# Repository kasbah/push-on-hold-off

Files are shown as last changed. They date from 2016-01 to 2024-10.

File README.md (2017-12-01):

See a preview of the board and buy the parts from the [kitspace.org page](https://kitspace.org/boards/github.com/kasbah/push-on-hold-off/). 

A power switch using a push button. It turns on with a single press and only turns off when you hold the button down. This could be used to get functionality similar to most laptops where a single press when on will initiate a "soft" shutdown but you can force a "hard" shutdown by holding it down.

The circuit is from [this article](http://www.mosaic-industries.com/embedded-systems/microcontroller-projects/electronic-circuits/push-button-switch-turn-on/latching-toggle-power-switch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).

The board is my own design and features:

- Standard 0.1" spacing, fits neatly onto a breadboard
- On-board button (and pins to connect your own)
- Two LEDs indicate input and output power
- Configurable to automatically turn on or stay off on initial power through a solder jumper (auto-off is the default)
- Can switch 3-20V and up to 4A

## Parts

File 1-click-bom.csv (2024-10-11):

References | Qty | Description | Manufacturer | MPN | Manufacturer | MPN | Manufacturer | MPN | Manufacturer | MPN | Manufacturer | MPN | Digikey | Mouser | RS | Newark | Farnell | LCSC | JLC Assembly
C1 | 1 | 1uF 0603 X5R | Murata | GRM188R71E224KA88D | KEMET | C0603C105K8PACTU | Yageo | CC0603KRX5R6BB105 |  |  |  |  | 399-C0603C105K8PAC7867DKR-ND | 603CC603KRX5R6BB105 | 4612708 | 91R0949 | 9402080 | C77051
C2 | 1 | 10uF 0603 X5R | TDK | C1608X5R1A106M080AC |  | 06036D106MAT2A | AVX | 06036D106MAT2A | TDK | C1608X5R0J106K080AB | TDK | C1608X5R1A106K080AC | 478-5318-6-ND | 810C1608X5R1A106K | 7882887P | 04X3239 | 2211164 | C3877917
C4 | 1 | 0.1uF 0603 X5R | Kemet | C0603C104K5RACTU | Murata | GRM033R60J104KE19D | KEMET | C0603C104K5RACTU |  |  |  |  | 490-3167-6-ND | 81GRM033R60J104KE19 | 8015347 | 72J5992 | 1288255 | C127833
D1 | 1 | Diode MiniMELF |  | LL4148 | onsemi | FDLL4148 | Diotec | LL4148 | onsemi | LL4148 |  |  | LL4148FSCT-ND | 512LL4148 | 6708823 | 14M6003 | 2356382 | C3011166
LED1,LED2 | 2 | 0603 20mA yellow | Rohm | SML-D12Y8WT86 | Dialight | 598-8040-107F | Dialight | 598-8150-107F | ROHM | SML-D12Y8WT86 |  |  | 350-2032-6-ND | 755SMLD12Y8WT86 | 7008039P | 75R0585 | 1867104 | C2840179
Q1 | 1 | 30V Vds, 3A Id, Dual HEXFET MOSFET | International Rectifier | IRF7309PBF | Infineon | IRF7309TRPBF |  |  |  |  |  |  | IRF7309PBFTR-ND | 942IRF7309TRPBF | 8268866 | 19K8239 | 2468006 | C3289674
R1 | 1 | 10k 0603 | Vishay | CRCW060310K0JNEA | Vishay | CRCW060310K0JNEAIF |  |  |  |  |  |  | 541-10KAQCT-ND | 71CRCW060310K0JNEAI | 8206928 | 52K8066 | 1739174 | C169103
R2,R4 | 2 | 100k 0603 | Vishay | CRCW0603100KJNEA | Vishay | CRCW0603100KJNEAIF |  |  |  |  |  |  | 541-100KAQDKR-ND | 71CRCW0603100KJNAIF | 8206916P | 59M6763 | 1692517 | C844723
R3 | 1 | 300k 0603 | Vishay | CRCW0603300KFKEA | Yageo | RC0603JR-07300KL |  |  |  |  |  |  | 311-300KGRCT-ND | 603RC0603JR07300KL | 6790178 | 52K8409 | 3495948 | C844772
R5, R6 | 2 | 1k 0603 | Yageo | RC0805FR-071KL |  |  |  |  |  |  |  |  | 311-1.00KCRDKR-ND | 603RC0805FR071KL | 6183583 | 82K7536 | 9237496 | C95781
SW1 | 1 | Tactile switch |  | FSM2JSMA | TE Connectivity | 2-1437565-7 |  |  |  |  |  |  | 450-1130-ND | 506FSM2JSMA | 4791491P | 92F2864 | 3801287 | C7193797

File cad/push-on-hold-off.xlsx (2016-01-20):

 |  |  |  |  |  |  | Board Qty: | 100
 |  |  |  |  |  |  | Total Cost: | $0.00 |  |  |  | $0.00 |  |  |  |  |  | $0.00 |  |  |  |  |  | $0.00
 |  |  |  |  |  |  | Unit Cost: | $0.00
Global Part Info |  |  |  |  |  |  |  |  | Digi-Key |  |  |  |  |  | Mouser |  |  |  |  |  | Newark
Refs | Value | Desc | Footprint | Manf | Manf# | Qty | Unit$ | Ext$ | Avail | Purch | Unit$ | Ext$ | Cat# | Doc | Avail | Purch | Unit$ | Ext$ | Cat# | Doc | Avail | Purch | Unit$ | Ext$ | Cat# | Doc
SW1 | SW_PUSH_SMALL |  |  |  |  | 0 | $0.00 | $0.00
C1 | 1uF |  |  |  |  | 0 | $0.00 | $0.00
C2 | 10uF |  |  |  |  | 0 | $0.00 | $0.00
R3 | 300k |  |  |  |  | 0 | $0.00 | $0.00
Q1 | IRF7309IPBF |  | SO-8 |  |  | 0 | $0.00 | $0.00
R2,R4 | 100k |  |  |  |  | 0 | $0.00 | $0.00
R1 | 10k |  |  |  |  | 0 | $0.00 | $0.00
P1,P2 | CONN_01X04 |  |  |  |  | 0 | $0.00 | $0.00
D1 | D |  |  |  |  | 0 | $0.00 | $0.00
 |  |  |  |  |  |  |  |  |  | 0 | 0 | 0 |  |  |  | 0 | 0 | 0 |  |  |  | 0 | 0 | 0
 |  |  |  |  |  |  |  |  |  | 0 | 0 | 0 |  |  |  | 0 | 0 | 0 |  |  |  | 0 | 0 | 0
 |  |  |  |  |  |  |  |  |  | 0 | 0 | 0 |  |  |  | 0 | 0 | 0 |  |  |  | 0 | 0 | 0
 |  |  |  |  |  |  |  |  |  | 0 | 0 | 0 |  |  |  | 0 | 0 | 0 |  |  |  | 0 | 0 | 0
 |  |  |  |  |  |  |  |  |  | 0 | 0 | 0 |  |  |  | 0 | 0 | 0 |  |  |  | 0 | 0 | 0
 |  |  |  |  |  |  |  |  |  | 0 | 0 | 0 |  |  |  | 0 | 0 | 0 |  |  |  | 0 | 0 | 0
 |  |  |  |  |  |  |  |  |  | 0 | 0 | 0 |  |  |  | 0 | 0 | 0 |  |  |  | 0 | 0 | 0
 |  |  |  |  |  |  |  |  |  | 0 | 0 | 0 |  |  |  | 0 | 0 | 0 |  |  |  | 0 | 0 | 0
 |  |  |  |  |  |  |  |  |  | 0 | 0 | 0 |  |  |  | 0 | 0 | 0 |  |  |  | 0 | 0 | 0

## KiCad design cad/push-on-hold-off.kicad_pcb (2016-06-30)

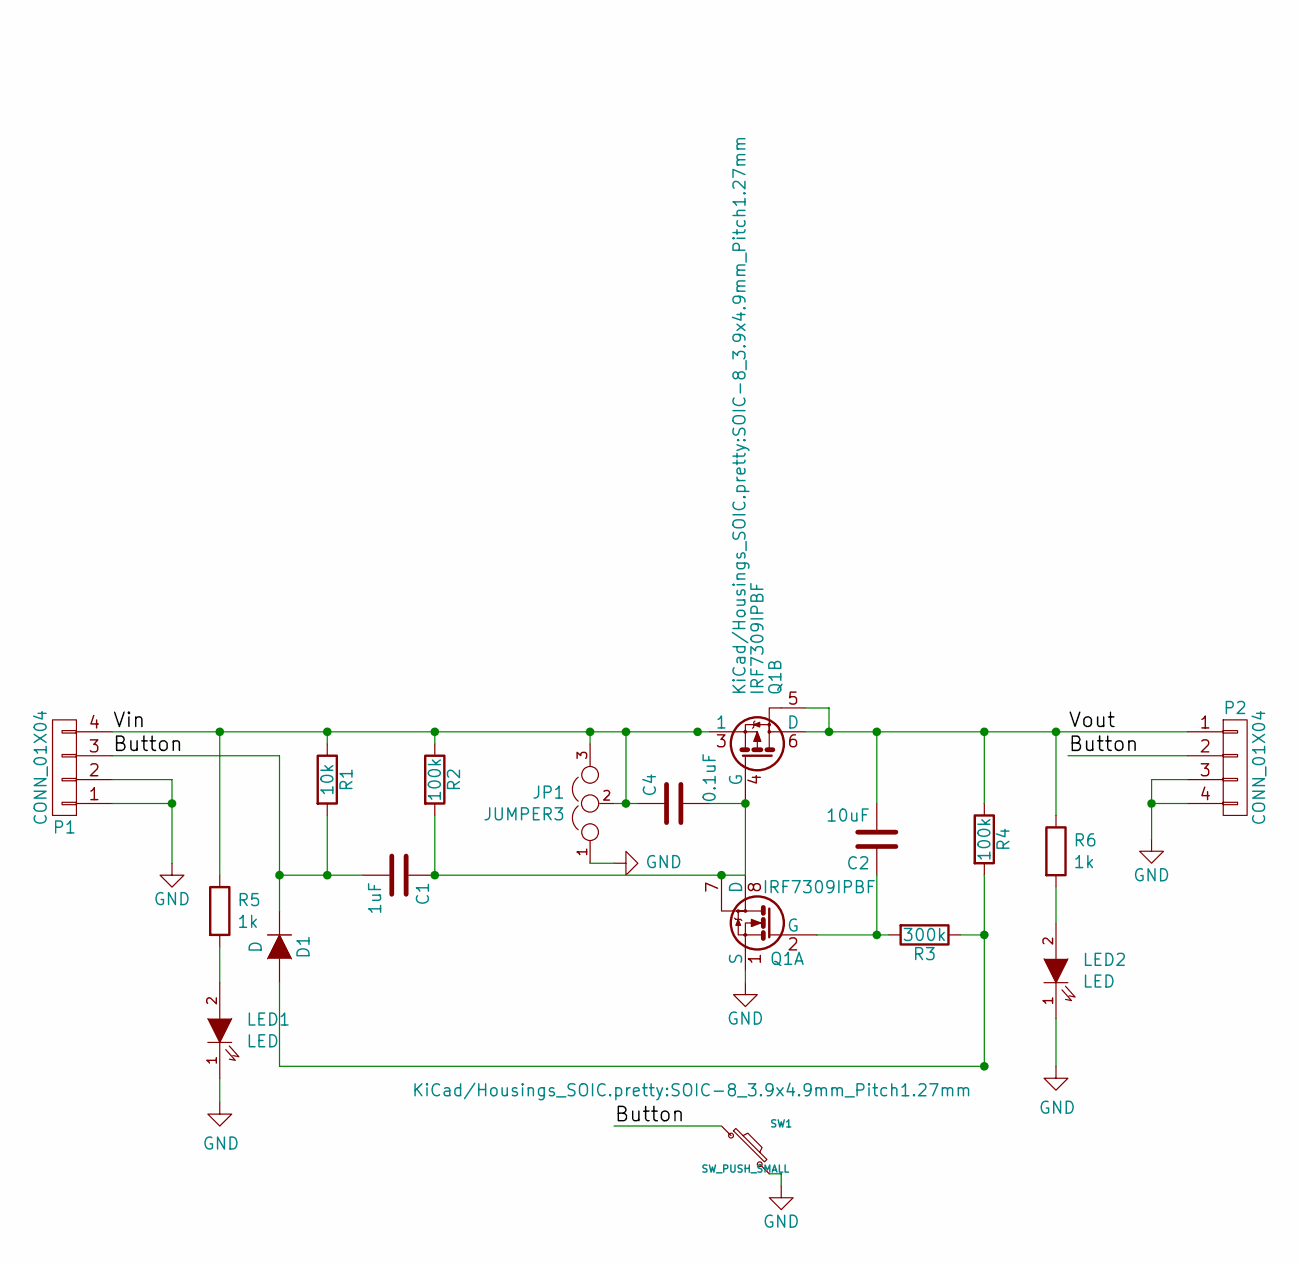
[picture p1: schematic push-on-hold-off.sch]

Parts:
C1: 1uF; C_0603_HandSoldering; MPN GRM188R71E224KA88D; Digikey 490-3290-1-ND
C2: 10uF; C_0603_HandSoldering; MPN C1608X5R1A106M080AC; Digikey 445-6853-1-ND
C4: 0.1uF; C_0603_HandSoldering; MPN C0603C104K5RACTU; Digikey 399-5089-1-ND
D1: D; MiniMELF_Handsoldering; MPN LL4148; Digikey LL4148FSCT-ND
JP1: JUMPER3; SOLDER-JUMPER_2-WAY
LED1, LED2: LED; R_0603_HandSoldering; MPN SML-D12Y8WT86; Digikey 511-1582-1-ND
P1, P2: CONN_01X04; Pin_Header_Straight_1x04
Q1: IRF7309IPBF; SOIC-8_3.9x4.9mm_Pitch1.27mm; MPN IRF7309PBF; Digikey IRF7309PBFCT-ND
R1: 10k; R_0603_HandSoldering; MPN CRCW060310K0JNEA; Digikey 541-10KGCT-ND
R2, R4: 100k; R_0603_HandSoldering; MPN CRCW0603100KJNEA; Digikey 541-100KGCT-ND
R3: 300k; R_0603_HandSoldering; MPN CRCW0603300KFKEA; Digikey 311-300KGRCT-ND
R5: 1k; R_0603_HandSoldering; MPN RC0805FR-071KL; Digikey 311-1.00KCRCT-ND
R6: 1k; R_0603_HandSoldering
SW1: SW_PUSH_SMALL; FSM2JSMA; MPN FSM2JSMA; Digikey 450-1130-ND

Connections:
/Button: C1.2, D1.1 (K), P1.3, P2.2, R1.2, SW1.1
/Vin: C4.1, JP1.2, JP1.3, P1.4, Q1.3 (1), R1.1, R2.1, R5.1
/Vout: C2.2, P2.1, Q1.5, Q1.6 (D), R4.1, R6.1
GND: JP1.1, LED1.1 (K), LED2.1 (K), P1.1, P1.2, P2.3, P2.4, Q1.1 (S), SW1.2
unnamed: C1.1, C4.2, Q1.4 (G), Q1.7, Q1.8 (D), R2.2
unnamed: C2.1, Q1.2 (G), R3.2
unnamed: D1.2 (A), R3.1, R4.2
unnamed: LED1.2 (A), R5.2
unnamed: LED2.2 (A), R6.2

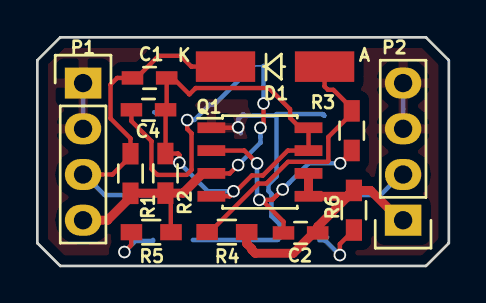
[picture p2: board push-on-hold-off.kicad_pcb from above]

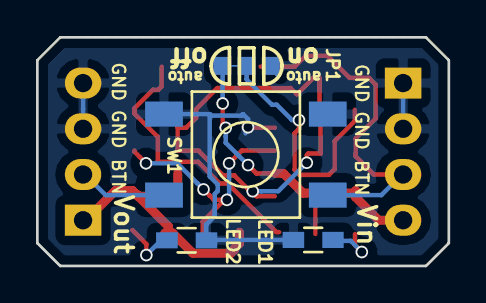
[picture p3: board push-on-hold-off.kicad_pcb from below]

Board: 2 copper layers, 22.9 x 12.7 mm, 17 parts (4 on the bottom side), 9 nets.

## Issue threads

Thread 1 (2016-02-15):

U1 footprint too wide

kasbah, 2016-02-15:
It's still solderable, just, but it could really be narrower. Check the datasheet.

Closed 2016-06-30.

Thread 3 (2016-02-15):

Bottom silkscreen should be flipped

kasbah, 2016-02-15:
So that when reading it with the switch facing you, power flow is left to right.

Closed 2016-06-30.

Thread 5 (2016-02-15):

Circuit can be switched on by bridging button input to Vout with your finger

kasbah, 2016-02-15:
Is this a bug or a feature?

kasbah, 2016-02-15:
This seems to only happen without a load on Vout. Tested with a 120Ohm and 22k load and it doesn't happen with those.

Closed 2016-02-15.

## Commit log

2016-01-20 Annotate schematic
    [push-on-hold-off.sch]
2016-01-20 Start layout
    [push-on-hold-off.kicad_pcb, push-on-hold-off.sch, push-on-hold-off.xlsx]
2016-01-20 Do some placing and draw outline
    [push-on-hold-off.kicad_pcb]
2016-01-20 Route most components
    [push-on-hold-off.kicad_pcb]
2016-01-20 Finish routing, add fills
    [push-on-hold-off.kicad_pcb]
2016-01-20 Add BOM, gerbers and kitnic.yaml
    [1-click-BOM.tsv, _saved_push-on-hold-off.sch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]
2016-01-20 Plot outline
    [push-on-hold-off-B_Cu.gbl, push-on-hold-off-B_Mask.gbs, push-on-hold-off-B_SilkS.gbo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]
2016-01-20 Add silkscreen connection reference
    [_saved_push-on-hold-off.sch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]
2016-01-20 Adjust gnd reference
    [push-on-hold-off.kicad_pcb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]
2016-01-26 Increase vias to 0.5mm drill with 0.7mm pad
    [push-on-hold-off-B_Cu.gbl, push-on-hold-off-B_Mask.gbs, push-on-hold-off-B_SilkS.gbo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]
2016-06-07 Add auto/on off caps and change Q1 footprint
    [push-on-hold-off.sch]
2016-06-07 Switch diode to bigger package
    [push-on-hold-off.sch]
2016-06-07 Add a jumper to configure auto on/off
    [push-on-hold-off.kicad_pcb, push-on-hold-off.sch]
2016-06-09 Use custom footprint paths and add LEDs
    [push-on-hold-off.sch]
2016-06-09 Switch button footprint to match BOM
    [push-on-hold-off.kicad_pcb, push-on-hold-off.sch]
2016-06-09 Sort button-side of board
    [push-on-hold-off.kicad_pcb, push-on-hold-off.sch]
2016-06-10 Switch diode to a mini-melf
    [1-click-bom.tsv, push-on-hold-off.kicad_pcb, push-on-hold-off.sch]
2016-06-10 Route the board
    [push-on-hold-off.kicad_pcb, push-on-hold-off.sch]
2016-06-10 Sort out silkscreen and plot
    [push-on-hold-off-B.Cu.gbl, push-on-hold-off-B.Mask.gbs, push-on-hold-off-B.SilkS.gbo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]
2016-06-10 Switch rendering colour for kitnic
2016-06-10 Re-plot with new ex
    [push-on-hold-off-B.Cu.gbr, push-on-hold-off-B.Mask.gbr, push-on-hold-off-B.SilkS.gbr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]
2016-06-10 Re-plot with protel extensions
    [push-on-hold-off-B.Cu.gbl, push-on-hold-off-B.Mask.gbs, push-on-hold-off-B.SilkS.gbo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]
2016-06-10 Get rid of old csv
    [push-on-hold-off.csv]
2016-06-11 Update BOM
    [1-click-bom.tsv, push-on-hold-off.sch]
2016-06-11 Extract bom into schematic
    [push-on-hold-off.sch]
2016-06-30 Fix auto-on jumper which was supposed to be to ground
    [push-on-hold-off.kicad_pcb, push-on-hold-off.sch]
2016-06-30 Re-plot gerbers
    [push-on-hold-off-B.Cu.gbl, push-on-hold-off-B.Mask.gbs, push-on-hold-off-B.SilkS.gbo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]
2022-06-21 Update bill of materials
    [1-click-bom.csv, 1-click-bom.tsv]
2024-10-11 Add LCSC part numbers (#7)
    [1-click-bom.csv]
